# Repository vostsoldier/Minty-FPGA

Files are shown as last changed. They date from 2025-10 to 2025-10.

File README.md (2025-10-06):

# Minty - A ECP5 based devboard with DDR3 RAM
## An introduction
Hey fellas it's Technical here with a cool beans board!!!
I wanted to experiment with FPGAs and RAM at the same time, so I thought, why not just combine the two onto one board!
What a great idea right!!! Hahahahahahhahaha!
But yeah thats how this board came to be...
At the time of writing (10/5/25), the board only has a few key parts needed for it to function..
HOWEVER, I am planning to put more cool stuff onto it, as I have like 150 IO pins left lol...
Feel free to DM technical_. on the Hack Club slack if you have any ideas for what to put!!!

## Features (As of 10/5/25)
- Lattice ECP5 FPGA
  * 44k LUTS
  * 1944 KiB of Embedded Memory
  * 351 KiB of RAM
- DDR3 RAM
  * 2GB
  * DDR3??
- 100 Mhz clock (probably)
- Snazzy Name

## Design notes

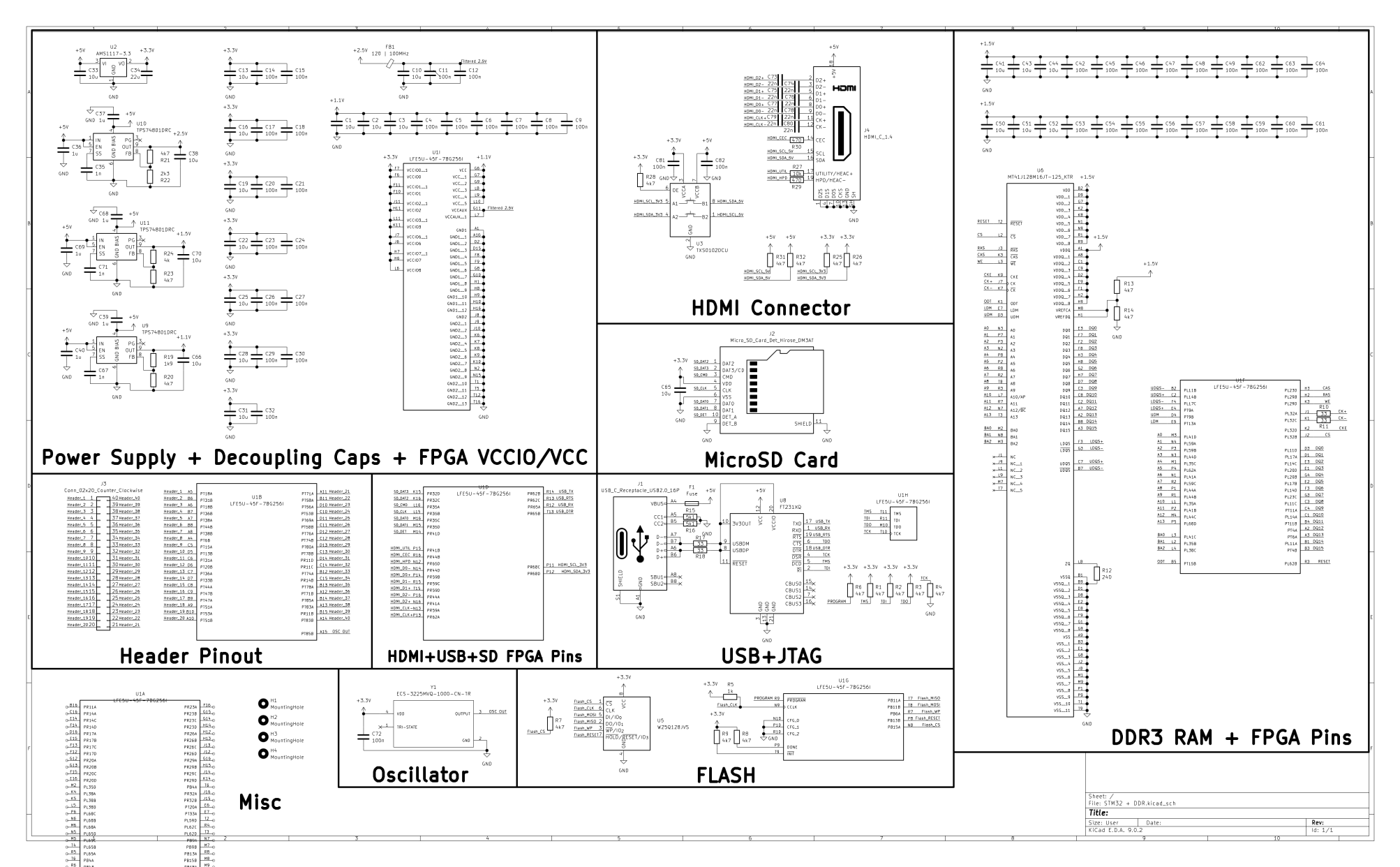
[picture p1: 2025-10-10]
Schematic Image/Minty_Schematic.png

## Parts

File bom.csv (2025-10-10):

Id | Designator | Footprint | Quantity | Designation | LCSC # | Price/unit | Total Price
1 | C35, C67, C71 | 0402_1005 | 3 | 1n | C1523 | 0.0011 | 1.5033
2 | C73, C74, C75, C76, C77, C78, C79, C80 | 0201_0603 | 8 | 22n | C161473 | 0.0076 | 1.5608
3 | C4, C5, C6, C7, C8, C9, C11, C12, C14, C15, C17, C18, C20, C21, C23, C24, C26, C27, C29, C30, C32, C42, C45, C46, C47, C48, C49, C53, C54, C55, C56, C57, C58, C59, C60, C61, C62, C63, C64, C72, C81, C82 | 0201_0603 | 41 | 100n | C49062 | 0.0013 | 1.5533
4 | C36, C37, C39, C40, C68, C69 | 0603_1608 | 6 | 1u | C15849 | 0.0047 | 1.5282
5 | C65 | 0402_1005 | 1 | 10u | C15525 | 0.005 | 1.505
6 | C10, C33, C38, C66, C70 | 0603_1608 | 5 | 10u | C19702 | 0.0056 | 1.528
7 | C34 | 0603_1608 | 1 | 22u | C59461 | 0.0086 | 1.5086
8 | R10, R11, R17, R18 | 0402_1005 | 4 | 33 | C25105 | 0.0006 | 1.5024
9 | R12, R33 | 0603_1608 | 2 | 240 | C23350 | 0.0007 | 1.5014
10 | R29, R30 | 0402_1005 | 2 | 470 | C17710 | 0.0018 | 1.5036
11 | R5 | 0402_1005 | 1 | 1k | C11702 | 0.0005 | 1.5005
12 | R19, R22, R24, R34, | 0402_1005 | 4 | 2k | C4109 | 0.0005 | 1.502
13 | R1, R2, R3, R4, R6, R7, R8, R9, R13, R14, R20, R21, R23, R25, R26, R28, R31, R32 | 0201_0603 | 18 | 4k7 | C138135 | 0.0008 | 1.5144
14 | R15, R16 | 0402_1005 | 2 | 5k1 | C11702 | 0.0005 | 1.501
15 | R27 | 0402_1005 | 1 | 10k | C25744 | 0.0005 | 1.5005
16 | FB1 | 0603_1608 | 1 | 120 | 100MHz | C14709 | 0.0064 | 1.5064
17 | F1 | 0603_1608 | 1 | Fuse | C210357 | 0.0347 | 1.5347
18 | U9, U10, U11 | VSON-10-1EP_3x3mm_P0.5mm_EP1.65x2.4mm_ThermalVias | 3 | TPS74801DRC | C105263 | 0.2225 | 2.1675
19 | U2 | SOT-223-3_TabPin2 | 1 | AMS1117-3.3 | C6186 | 0.1622 | 1.6622
20 | U5 | SOIC-8_5.3x5.3mm_P1.27mm | 1 | W25Q128JVS | C97521 | 1.0605 | 2.5605
21 | U8 | QFN-20-1EP_4x4mm_P0.5mm_EP2.5x2.5mm | 1 | FT231XQ | C132159 | 4.503 | 6.003
22 | U3 | VSSOP-8_2.3x2mm_P0.5mm | 1 | TXS0102DCU | C53434 | 0.1266 | 1.6266
23 | Y1 | OSC_ECS-3225MVQ-1000-CN-TR | 1 | ECS-3225MVQ-1000-CN-TR | C2595933 | 2.217 | 3.717
24 | U1 | BGA256C80P16X16_1400X1400X170 | 1 | LFE5U-45F-7BG256I | C1550826 | 15.8235 | 17.3235
25 | U6 | BGA96C80P6X16_800X1400X120 | 1 | MT41J128M16JT-125_KTR | C426885 | 3.36 | 4.86
26 | J1 | USB_C_Receptacle_GCT_USB4105-xx-A_16P_TopMnt_Horizontal | 1 | USB_C_Receptacle_USB2.0_16P | C2765186 | 0.0563 | 1.5563
27 | J2 | microSD_HC_Hirose_DM3AT-SF-PEJM5 | 1 | Micro_SD_Card_Det_Hirose_DM3AT | C114218 | 1.203 | 2.703
28 | J4 | AMPHENOL_10029449-11RLF | 1 | HDMI_C_1.4 | C427307 |  | 139.8674

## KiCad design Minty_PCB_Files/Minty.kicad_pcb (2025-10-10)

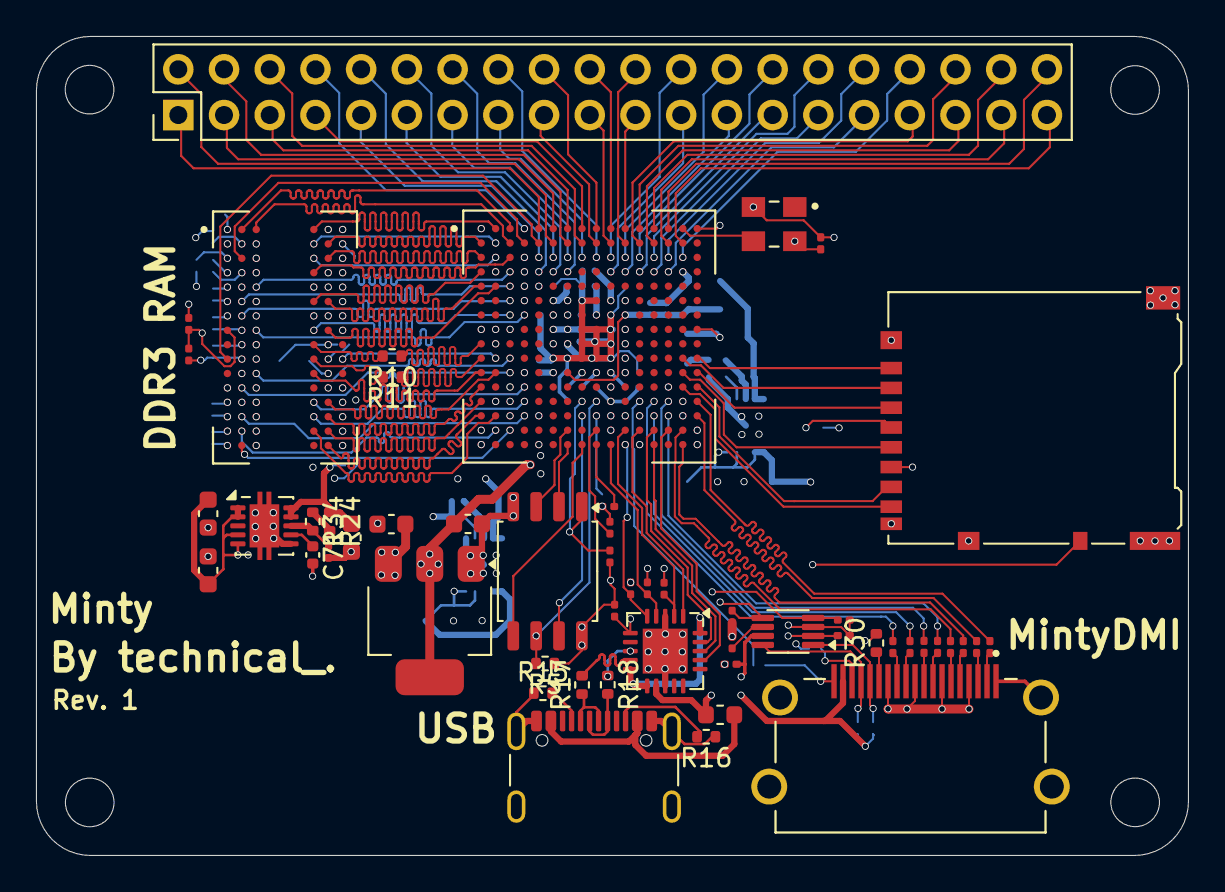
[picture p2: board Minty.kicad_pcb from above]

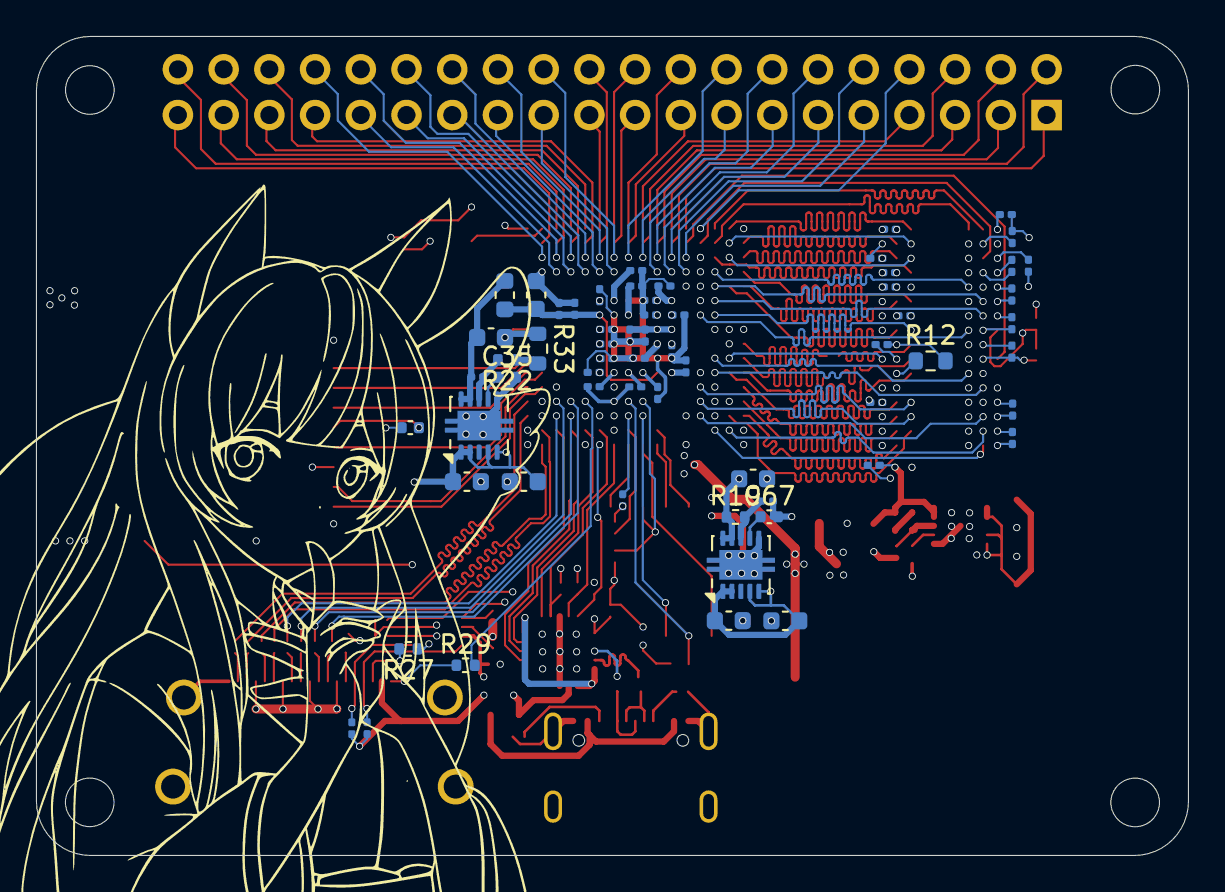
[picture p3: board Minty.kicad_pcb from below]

Board: 6 copper layers, 64.0 x 45.5 mm, 119 parts (62 on the bottom side), 165 nets.

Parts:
C4, C5, C6, C7, C8, C9, C11, C12, C14, C15, C17, C18, C20, C21, C23, C24, C26, C27, C29, C30, C32, C42, C45, C46, C47, C48, C49, C53, C55, C56, C57, C58, C59, C60, C61, C62, C63, C64, C72, C81, C82: 100n; C_0201_0603Metric
C10, C33, C38, C66, C70: 10u; C_0603_1608Metric
C34: 22u; C_0603_1608Metric
C35, C67, C71: 1n; C_0402_1005Metric
C36, C37, C39, C40, C68, C69: 1u; C_0603_1608Metric
C65: 10u; C_0402_1005Metric
C73, C74, C75, C76, C77, C78, C79, C80: 22n; C_0201_0603Metric
F1: Fuse; Fuse_0603_1608Metric
FB1: 120 | 100MHz; L_0603_1608Metric
H1, H2, H3, H4: MountingHole; MountingHole_2.7mm_M2.5
J1: USB_C_Receptacle_USB2.0_16P; USB_C_Receptacle_GCT_USB4105-xx-A_16P_TopMnt_Horizontal
J2: Micro_SD_Card_Det_Hirose_DM3AT; microSD_HC_Hirose_DM3AT-SF-PEJM5
J3: Conn_02x20_Counter_Clockwise; PinHeader_2x20_P2.54mm_Vertical
J4: HDMI_C_1.4; AMPHENOL_10029449-111RLF
R1, R2, R3, R4, R6, R7, R8, R9, R13, R14, R20, R21, R23, R25, R26, R28, R31, R32: 4k7; R_0201_0603Metric
R5: 1k; R_0402_1005Metric
R10, R11, R17, R18: 33; R_0402_1005Metric
R12, R33: 240; R_0603_1608Metric
R15, R16: 5k1; R_0402_1005Metric
R19, R22, R24, R34: 2k; R_0402_1005Metric
R27: 10k; R_0402_1005Metric
R29, R30: 470; R_0402_1005Metric
U1: LFE5U-45F-7BG256I; BGA256C80P16X16_1400X1400X170
U2: AMS1117-3.3; SOT-223-3_TabPin2
U3: TXS0102DCU; VSSOP-8_2.3x2mm_P0.5mm
U5: W25Q128JVS; SOIC-8_5.3x5.3mm_P1.27mm
U6: MT41J128M16JT-125_KTR; BGA96C80P6X16_800X1400X120
U8: FT231XQ; QFN-20-1EP_4x4mm_P0.5mm_EP2.5x2.5mm
U9, U10, U11: TPS74801DRC; VSON-10-1EP_3x3mm_P0.5mm_EP1.65x2.4mm_ThermalVias
Y1: ECS-3225MVQ-1000-CN-TR; OSC_ECS-3225MVQ-1000-CN-TR

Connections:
+1.1V: C4.1, C5.1, C6.1, C7.1, C8.1, C9.1, C66.1, R19.1, U1.G6 (VCC), U1.G7 (VCC__1), U1.G9 (VCC__2), U1.L8 (VCC__3), U1.L9 (VCC__4), U1.L10 (VCC__5), U9.9 (OUT), U9.10 (OUT)
+1.5V: C42.1, C45.1, C46.1, C47.1, C48.1, C49.1, C53.1, C55.1, C56.1, C57.1, C58.1, C59.1, C60.1, C61.1, C62.1, C63.1, C64.1, C70.1, R13.1, R24.1, U6.A1 (VDDQ), U6.A8 (VDDQ__1), U6.B2 (VDD), U6.C1 (VDDQ__2), U6.C9 (VDDQ__3), U6.D2 (VDDQ__4), U6.D9 (VDD__1), U6.E9 (VDDQ__5), U6.F1 (VDDQ__6), U6.G7 (VDD__2), U6.H2 (VDDQ__7), U6.H9 (VDDQ__8), U6.K2 (VDD__3), U6.K8 (VDD__4), U6.N1 (VDD__5), U6.N9 (VDD__6), U6.R1 (VDD__7), U6.R9 (VDD__8), U11.9 (OUT), U11.10 (OUT)
+2.5V: C38.1, FB1.1, R21.2, U10.9 (OUT), U10.10 (OUT)
+3.3V: C14.1, C15.1, C17.1, C18.1, C20.1, C21.1, C23.1, C24.1, C26.1, C27.1, C29.1, C30.1, C32.1, C34.1, C65.2, C72.1, C81.1, J2.4 (VDD), R1.1, R2.1, R3.1, R5.1, R6.1, R7.1, R8.1, R9.1, R25.1, R26.1, R28.1, U1.F6 (VCCIO0), U1.F7 (VCCIO0__1), U1.F10 (VCCIO1), U1.F11 (VCCIO1__1), U1.H6 (VCCIO7), U1.H7 (VCCIO7__1), U1.H11 (VCCIO2), U1.J6 (VCCIO6), U1.J7 (VCCIO6__1), U1.J11 (VCCIO2__1), U1.K11 (VCCIO3), U1.L6 (VCCIO8), U1.L11 (VCCIO3__1), U2.2 (VO), U3.3 (VCCA), U5.8 (VCC), Y1.4 (VDD)
+5V: C33.1, C36.1, C37.2, C39.2, C40.1, C68.2, C69.1, C82.1, F1.2, J4.18 (+5V), R31.1, R32.1, U2.3 (VI), U3.7 (VCCB), U8.12 (VCC), U9.1 (IN), U9.2 (IN), U9.4 (BIAS), U9.5 (EN), U10.1 (IN), U10.2 (IN), U10.4 (BIAS), U10.5 (EN), U11.1 (IN), U11.2 (IN), U11.4 (BIAS), U11.5 (EN)
/A0: U1.M3 (PL41D), U6.N3 (A0)
/A1: U1.N4 (PL59A), U6.P7 (A1)
/A2: U1.P3 (PL59B), U6.P3 (A2)
/A3: U1.N3 (PL44D), U6.N2 (A3)
/A4: U1.M1 (PL35C), U6.P8 (A4)
/A5: U1.P4 (PL62A), U6.P2 (A5)
/A6: U1.N1 (PL41A), U6.R8 (A6)
/A7: U1.R2 (PL59C), U6.R2 (A7)
/A8: U1.P1 (PL44A), U6.T8 (A8)
/A9: U1.R1 (PL44B), U6.R3 (A9)
/A10: U1.L1 (PL35A), U6.L7 (A10/AP)
/A11: U1.P2 (PL41B), U6.R7 (A11)
/A12: U1.M4 (PL44C), U6.N7 (A12/~BC)
/A13: U1.P5 (PL68D), U6.T3 (A13)
/BA0: U1.L3 (PL41C), U6.M2 (BA0)
/BA1: U1.L2 (PL35B), U6.N8 (BA1)
/BA2: U1.L4 (PL38C), U6.M3 (BA2)
/CAS: U1.H3 (PL23D), U6.K3 (~CAS)
/CK+: R10.2, U6.J7 (CK)
/CK-: R11.2, U6.K7 (~CK)
/CKE: U1.K2 (PL32D), U6.K9 (CKE)
/CS: U1.J2 (PL32B), U6.L2 (~CS)
/DQ0: U1.D3 (PL11D), U6.E3 (DQ0)
/DQ1: U1.D1 (PL17A), U6.F7 (DQ1)
/DQ2: U1.E3 (PL14C), U6.F2 (DQ2)
/DQ3: U1.E1 (PL20D), U6.F8 (DQ3)
/DQ4: U1.G4 (PL20B), U6.H3 (DQ4)
/DQ5: U1.E2 (PL17B), U6.H8 (DQ5)
/DQ6: U1.F3 (PL14D), U6.G2 (DQ6)
/DQ7: U1.G3 (PL23C), U6.H7 (DQ7)
/DQ8: U1.C3 (PL11C), U6.D7 (DQ8)
/DQ9: U1.C4 (PT11A), U6.C3 (DQ9)
/DQ10: U1.C1 (PL14A), U6.C8 (DQ10)
/DQ11: U1.B4 (PT11B), U6.C2 (DQ11)
/DQ12: U1.A2 (PT4A), U6.A7 (DQ12)
/DQ13: U1.A3 (PT6A), U6.A2 (DQ13)
/DQ14: U1.B1 (PL11A), U6.B8 (DQ14)
/DQ15: U1.B3 (PT4B), U6.A3 (DQ15)
/Filtered 2.5V: C10.1, C11.1, C12.1, FB1.2, U1.G11 (VCCAUX), U1.L7 (VCCAUX__1)
/Flash_CLK: R5.2, U1.N9 (CCLK), U5.6 (CLK)
/Flash_CS: R7.2, U1.N8 (PB15A), U5.1 (~CS)
/Flash_MISO: U1.T7 (PB11A), U5.2 (DO/IO_{1})
/Flash_MOSI: U1.T8 (PB11B), U5.5 (DI/IO_{0})
/Flash_RESET: U1.P8 (PB13B), U5.7 (~HOLD/~RESET/IO_{3})
/Flash_WP: U1.R7 (PB6A), U5.3 (~WP/IO_{2})
/HDMI_CEC: R30.2, U1.R16 (PR44B)
/HDMI_CLK+: C79.2, U1.P13 (PR62A)
/HDMI_CLK-: C80.2, U1.N13 (PR59A)
/HDMI_D0+: C77.2, U1.P14 (PR59B)
/HDMI_D0-: C78.2, U1.N14 (PR44D)
/HDMI_D1+: C75.2, U1.T15 (PR59D)
/HDMI_D1-: C76.2, U1.R15 (PR59C)
/HDMI_D2+: C73.2, U1.N16 (PR41A)
/HDMI_D2-: C74.2, U1.P16 (PR44A)
/HDMI_HPD: R29.2, U1.N12 (PR65D)
/HDMI_SCL_3V3: R25.2, U1.P11 (PR68C), U3.5 (A1)
/HDMI_SCL_5V: J4.15 (SCL), R31.2, U3.1 (B2)
/HDMI_SDA_3V3: R26.2, U1.P12 (PR68D), U3.4 (A2)
/HDMI_SDA_5V: J4.16 (SDA), R32.2, U3.8 (B1)
/HDMI_UTIL: R27.1, U1.P15 (PR41B)
/Header_1: J3.1, U1.A5 (PT18A)
/Header_2: J3.2, U1.B6 (PT31B)
/Header_3: J3.3, U1.A6 (PT18B)
/Header_4: J3.4, U1.B7 (PT36B)
/Header_5: J3.5, U1.A7 (PT38A)
/Header_6: J3.6, U1.B8 (PT44B)
/Header_7: J3.7, U1.A8 (PT38B)
/Header_8: J3.8, U1.A4 (PT6B)
/Header_9: J3.9, U1.C5 (PT15A)
/Header_10: J3.10, U1.D5 (PT13B)
/Header_11: J3.11, U1.C6 (PT31A)
/Header_12: J3.12, U1.D6 (PT20B)
/Header_13: J3.13, U1.C7 (PT36A)
/Header_14: J3.14, U1.D7 (PT33B)
/Header_15: J3.15, U1.C8 (PT44A)
/Header_16: J3.16, U1.C9 (PT47B)
/Header_17: J3.17, U1.B9 (PT47A)
/Header_18: J3.18, U1.A9 (PT51A)
/Header_19: J3.19, U1.B10 (PT53A)
/Header_20: J3.20, U1.A10 (PT51B)
/Header_21: J3.21, U1.A11 (PT71A)
/Header_22: J3.22, U1.B11 (PT58A)
/Header_23: J3.23, U1.D10 (PT56A)
/Header_24: J3.24, U1.C10 (PT53B)
/Header_25: J3.25, U1.D11 (PT69A)
/Header_26: J3.26, U1.C11 (PT58B)
/Header_27: J3.27, U1.D12 (PT76A)
/Header_28: J3.28, U1.C12 (PT74B)
/Header_29: J3.29, U1.D13 (PT80A)
/Header_30: J3.30, U1.C13 (PT78B)
/Header_31: J3.31, U1.D14 (PR11D)
/Header_32: J3.32, U1.C14 (PR11C)
/Header_33: J3.33, U1.B12 (PT74A)
/Header_34: J3.34, U1.C15 (PR14B)
/Header_35: J3.35, U1.B13 (PT78A)
/Header_36: J3.36, U1.A12 (PT71B)
/Header_37: J3.37, U1.B14 (PT85A)
/Header_38: J3.38, U1.A13 (PT83A)
/Header_39: J3.39, U1.B15 (PR11B)
/Header_40: J3.40, U1.A14 (PT83B)
/LDM: U1.E5 (PT13A), U6.E7 (LDM)
/LDQS+: U1.E4 (PT9A), U6.F3 (LDQS)
/LDQS-: U1.F4 (PL17C), U6.G3 (~LDQS)
/ODT: U1.B5 (PT15B), U6.K1 (ODT)
/OSC OUT: U1.A15 (PT85B), Y1.3 (OUTPUT)
/PROGRAM: R6.2, U1.R9 (~PROGRAM)
/RAS: U1.H2 (PL29B), U6.J3 (~RAS)
/RESET: U1.R3 (PL62B), U6.T2 (~RESET)
/SD_CLK: J2.5 (CLK), U1.L15 (PR35B)
/SD_CMD: J2.3 (CMD), U1.L16 (PR35A)
/SD_DAT0: J2.7 (DAT0), U1.M16 (PR35C)
/SD_DAT1: J2.8 (DAT1), U1.M15 (PR35D)
/SD_DAT2: J2.1 (DAT2), U1.K16 (PR32C)
/SD_DAT3: J2.2 (DAT3/CD), U1.K15 (PR32D)
/SD_DET: J2.10 (DET_A), U1.M14 (PR41D)
/TCK: R4.1, U1.T10 (TCK), U8.4 (~DSR)
/TDI: R2.2, U1.R11 (TDI), U8.2 (~RI)
/TDO: R3.2, U1.M10 (TDO), U8.6 (~CTS)
/TMS: R1.2, U1.T11 (TMS), U8.5 (~DCD)
/UDM: U1.D4 (PT9B), U6.D3 (UDM)
/UDQS+: U1.C2 (PL14B), U6.C7 (UDQS)
/UDQS-: U1.B2 (PL11B), U6.B7 (~UDQS)
/USB_DTR: U1.T13 (PR65B), U8.18 (~DTR)
/USB_RTS: U1.R13 (PR62C), U8.19 (~RTS)
/USB_RX: U1.R12 (PR65A), U8.1 (RXD)
/USB_TX: U1.R14 (PR62B), U8.17 (TXD)
/WE: U1.K3 (PL29D), U6.L3 (~WE)
GND: C4.2, C5.2, C6.2, C7.2, C8.2, C9.2, C10.2, C11.2, C12.2, C14.2, C15.2, C17.2, C18.2, C20.2, C21.2, C23.2, C24.2, C26.2, C27.2, C29.2, C30.2, C32.2, C33.2, C34.2, C35.2, C36.2, C37.1, C38.2, C39.1, C40.2, C42.2, C45.2, C46.2, C47.2, C48.2, C49.2, C53.2, C55.2, C56.2, C57.2, C58.2, C59.2, C60.2, C61.2, C62.2, C63.2, C64.2, C65.1, C66.2, C67.2, C68.1, C69.2, C70.2, C71.2, C72.2, C81.2, C82.2, J1.A1 (GND), J1.B1 (GND), J1.S1 (SHIELD), J2.6 (VSS), J2.9 (DET_B), J2.11 (SHIELD), J4.1 (D2S), J4.4 (D1S), J4.7 (D0S), J4.10 (CKS), J4.13 (GND), R4.2, R12.2, R14.2, R15.1, R16.1, R20.2, R23.2, R33.1, U1.A1 (GND1), U1.A16 (GND1__1), U1.D2 (GND1__2), U1.D15 (GND1__3), U1.F8 (GND1__4), U1.F9 (GND1__5), U1.G8 (GND1__6), U1.G10 (GND1__7), U1.H1 (GND1__8), U1.H8 (GND1__9), U1.H9 (GND1__10), U1.H10 (GND1__11), U1.H16 (GND1__12), U1.J8 (GND2), U1.J9 (GND2__1), U1.J10 (GND2__2), U1.K6 (GND2__3), U1.K7 (GND2__4), U1.K8 (GND2__5), U1.K9 (GND2__6), U1.K10 (GND2__7), U1.N2 (GND2__8), U1.N10 (CFG_0), U1.N15 (GND2__9), U1.P10 (CFG_1), U1.R10 (CFG_2), U1.T1 (GND2__10), U1.T5 (GND2__11), U1.T12 (GND2__12), U1.T16 (GND2__13), U2.1 (GND), U3.2 (GND), U5.4 (GND), U6.A9 (VSS), U6.B1 (VSSQ), U6.B3 (VSS__1), U6.B9 (VSSQ__1), U6.D1 (VSSQ__2), U6.D8 (VSSQ__3), U6.E1 (VSS__2), U6.E2 (VSSQ__4), U6.E8 (VSSQ__5), U6.F9 (VSSQ__6), U6.G1 (VSSQ__7), U6.G8 (VSS__3), U6.G9 (VSSQ__8), U6.J2 (VSS__4), U6.J8 (VSS__5), U6.M1 (VSS__6), U6.M9 (VSS__7), U6.P1 (VSS__8), U6.P9 (VSS__9), U6.T1 (VSS__10), U6.T9 (VSS__11), U8.3 (GND), U8.13 (GND), U8.21 (GND), U9.6 (GND), U9.11 (GND), U10.6 (GND), U10.11 (GND), U11.6 (GND), U11.11 (GND), Y1.2 (GND)
unnamed: F1.1, J1.A4 (VBUS), J1.B4 (VBUS)
unnamed: J1.A5 (CC1), R15.2
unnamed: J1.B5 (CC2), R16.2
unnamed: J1.A6 (D+), J1.B6 (D+), R18.2
unnamed: J1.A7 (D-), J1.B7 (D-), R17.1
unnamed: J4.14 (CEC), R30.1
unnamed: C79.1, J4.11 (CK+)
unnamed: C80.1, J4.12 (CK-)
unnamed: C77.1, J4.8 (D0+)
unnamed: C78.1, J4.9 (D0-)
unnamed: C75.1, J4.5 (D1+)
unnamed: C76.1, J4.6 (D1-)
unnamed: C73.1, J4.2 (D2+)
unnamed: C74.1, J4.3 (D2-)
unnamed: J4.19 (HPD/HEAC-), R29.1
unnamed: J4.17 (UTILITY/HEAC+), R27.2
unnamed: R22.1, R33.2
unnamed: R24.2, R34.1
unnamed: R10.1, U1.J1 (PL32A)
unnamed: R11.1, U1.K1 (PL32C)
unnamed: R8.2, U1.P9 (DONE)
unnamed: R9.2, U1.T9 (~INIT)
unnamed: R28.2, U3.6 (OE)
unnamed: R13.2, R14.1, U6.H1 (VREFDQ), U6.M8 (VREFCA)
unnamed: R12.1, U6.L8 (ZQ)
unnamed: R17.2, R18.1, U8.8 (USBDP), U8.9 (USBDM), U8.10 (3V3OUT), U8.11 (~RESET), U8.20 (VCCIO)
unnamed: R19.2, R20.1, U9.8 (FB)
unnamed: C67.1, U9.7 (SS)
unnamed: R21.1, R22.2, U10.8 (FB)
unnamed: C35.1, U10.7 (SS)
unnamed: R23.1, R34.2, U11.8 (FB)
unnamed: C71.1, U11.7 (SS)

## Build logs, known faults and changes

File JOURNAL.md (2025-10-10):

<!--
  ===================    !!READ THIS NOTICE!!   ====================
  DO NOT edit this file manually. Your changes WILL BE OVERWRITTEN!
  This journal is auto generated and updated by Hack Club Blueprint.
  To edit this file, please edit your journal entries on Blueprint.
  ==================================================================
-->

This is my journal of the design and building process of **Minty FPGA**.  
You can view this journal in more detail on **Hack Club Blueprint** [here](https://blueprint.hackclub.com/projects/173).

## 10/4/2025 9:10 PM - Started the FPGA schematic + power source + flash memory!  



Added decoupling capacitors for VCCIO, VCC and a filtering system for VCCAUX.
Tied all relevant VSS/VSSQ pins to ground, as per standard practice.
Decided on components for the power source, and chose to use the AMS1117 (Fixed), for the main power supply, and then various TLV713xxPDBV modules for smaller voltage rails (DDR RAM + FPGA).
Chose the W25Q128JVS, as this was a flash that was supported by the ECP5.   

## 10/4/2025 9:14 PM - Finished flash memory + JTAG  



Added net labels and connected the pins of the flash memory (did not do WP or RESET as they don't have specific FPGA pins). 
Initializing the JTAG was easy, as they just needed a couple of pullups/pulldowns!
I also decided on the RAM module that I wanted to use, which was the MT41J128M16JT-125_KTR. This is a 2GB DDR3 memory, for only ~$3, which is actually pretty affordable!  

## 10/4/2025 9:18 PM - Finished RAM schematic + thoughts about potential routing.  




Building off of the RAM module that I chose, I took a look at the reference manual/datasheet, and mapped the pins to the particular FPGA pin that was needed!
I also added a bunch of decoupling caps since I needed a really stable and clean power source to the RAM. 
Address and Data pins did not have a specific pin to map to, so I assigned it in a logical way that would make it the most easiest to route. 
I also made sure to make a mental note to do impedance (50 ohms) and length matching.  

## 10/4/2025 9:24 PM - Routed the DDR3 RAM (DID NOT DO POWER YET)  

Screenshot 2025-10-04 at 9.19.26 PM.png
Screenshot 2025-10-04 at 9.19.43 PM.png
Screenshot 2025-10-04 at 9.19.54 PM.png
Screenshot 2025-10-04 at 9.20.00 PM.png

Keeping in mind the strict impedance (50 ohms) and length matching (clock + data + address traces), I started and finished the routing today. (This should be the most up to date thing for now). 
I put some 33 ohm resistors to improve ringing resistance, and provide a termination point for the clock signals. Address did not need resistors, even though they are "recommended" as the trace lengths were under 1 inch! 
I had to spam skew tuning because most traces had to be length matches and my eyes just see squiggly lines....
But yeah this was worth the effort and tomorrow I have to suffer doing power (backside of the board...)  

## 10/5/2025 10 AM - Finished DDR3 Routing + USB Serial Schema   




So I think I violated some common conventions of routing but here I am!!!
Sadly I had to do via on pad for the DDR3 ram power, since they are decouplings and I can't place them too far...
After that nightmare was over, I started on the USB + USB serial converter schematic since it was a pretty important portion to me! I took a look at the datasheet, and pin mapped relevantly!
I also did the microSD schematic since it was decently easy, and I was really familiar with it!
I'll probably start routing a bit later during the day!  

## 10/5/2025 1 PM - Routed USB + Flash Memory  



I finished routing all of the USB and flash memory components!!!
I didn't attach a picture, but I mapped all of the relevant usb/flash pins to FPGA GPIOs. I tried my best to fanout the BGA in a way that saved most of the GPIO pins. 
Remembering to keep 90 differential pair impedance for the USB traces, and thick traces for the power traces!
I still need to do power, which might take alot of time :pensive:!  

## 10/5/2025 4 PM - Placement + Routing of Caps + Power regulators  




For this journal entry, I finished doing all of the decoupling caps on the FPGA. Standard rule of 1 100n cap per power pin and a few 10u spread out. 
The decoupling cap layout is a bit messy, but it is what it is :///
I also did the routing of the power supply regulators. I didn't fully connect them to the FPGA/power plane yet, but it should just be a couple of copper pours and traces away!   

## 10/5/2025 7 PM - Revised power supply/regulation + routing (TY TO CYAO!!!)  




After talking with Cyao, a neighborhood FPGA expert, I realized that I could have optimized my component selection! 
Taking into account his feedback, I completely changed all of the TLV series *fixed* linear regulators to TPS series linear *adjustable* regulators. It added a few more discrete components, but it saved me a ton of money on JLC's extended part reel fee!
I didn't add vias to the GND pads of the modules, since I still had to figure out where I would place them, and how I would link them up to the FPGA.  

## 10/5/2025 8 PM - Finished routing all of the power yahoo  



As you can see in the picture, I finished routing and placing the linear regulator modules. It feels a bit unoptimized to me, but for now its pretty functional and it works!
I hate how there is empty space there, but it is a "oh well can't do much about it" moment.
I'll probably clean up the vias since they look uneven, but overall a decent idea. 
I forgot about the clock, so I have to make the schematic for that, but that is easy!!!
I feel like I need more of a bang on the board, so tomorrow will just be tidying up and thoughts!   

## 10/5/2025 11 PM - Created/Routed osc schematic + optimization  




I finally added the 100 MHz oscillator. I chose the ECS-3225MVQ-1000-CN-TR, since it was fairly cheap, but also reputable. The oscillation waves were very clean, suitable for my DDR3 clock references!
I also optimized my power supply placement a bit, as I realized I had just enough space to squeeze in my AMS-1117 (3.3V fixed). 
The design looked more clean overall!

I fixed some traces as well, opting for a more professional and efficient route. 

If you read this, I would appreciate it if you could DM me some ideas about what I should add next, like sensors or anything really cool!  

## 10/6/2025 11 AM - Finished routing microSD + QOL improvements!  



Heyo guys, I finished routing all of the microSD pins!!!
This part was a bit easy, since microSD doesn't need too much strict requirements, so I routed the traces cleanly, and made sure that they were decently length matchedish.
I was thinking about moving the USB, and moving a few components to make the board smaller, but I did not want to risk getting too much interference (two high speed signals right next to each other (DDR3 + USB is not a good combo)... 
I fixed up some traces, as I forgot to send 5V traces to the power regulators. I used a simple copper pour, (maybe three different copper pours on one layer is okay??) and did multiple vias + thick traces as the current was pretty big.  

## 10/6/2025 11:20 PM - Routed HDMI connector + schematic  




Okay before I start, I just want say. Cramming a HDMI connector into BGA pads is not fun. At all.
I basically removed the entire microsd for now, since HDMI had to be closer to the FPGA cuz signal priority + high speed signals etc etc... 
I'll probably put microSD at a later time, maybe above the HDMI connector. 
I still have some space for one more cool thing, so I need more ideas lol!!!  

## 10/6/2025 11:43 PM - Finished routing microSD (for real this time)  



So I finished routing the microSD component, and pin mapped to the preferred pins. I think that this will be the last major feature, and that I won't add any more... (maybe)...
I still need to connect a few power pins, so I will do some revisions + add a few LEDs tommorow!
Otherwise the board should be almost complete!!!  

## 10/7/2025 8 AM - Finished routing everything!!!!  



It's here!!! The finished routed version of the Minty board!!!
All I did were a few minor changes, such as cleaning up vias, improving traces, connecting GND + Power pins. 
Not too much, but it was definitely the more annoying portion...
After I clean up my schematic and get reviews from professionals, I should be able to ship the board!!!  

## 10/7/2025 6 PM - Added pin headers + cleaned up routing + other QOL  



I added a 40 pin header, perfect for people who want to experiment using io pins!
Added a couple of mounting holes and filleted edge cuts!
Moved a couple of components around a bit to make the design look a bit more cleaner, and messed with the traces to make them look more clean/efficent. 
I may or may not change the FPGA decoupling caps later, as it is a bit messyish/  

## 10/8/2025 - Polished up the schematic + waiting for professional review  



So after last update, where I finished up the routing, this time I tried to fix up the schematic to make it look pretty for professionals to review. I sent it over to KiCAD's official server, where experienced people will look at it!

Cleaning up the schematic was ridicously annoying, as I had to move all of the dang FPGA pins around... That was a whole time with carpal tunnel...

After I get a review of my schematic + routing, I'll fix all of the errors on the next update!  

## 10/9/2025 - Feedback implementation + silkscreen  




I got feedback from professionals from the KiCAD official server, and there were no major faults!!! Hip hip hooray lol!!!
I fixed a few things like adding more vias since they don't cost anything to add, fixing up some traces, double checking that values were correct, and adding some silkscreen so that the board looked nice/I knew what was what!  

## 10/10/2025 - Finished BOM + Gerbers  



Hey everyone!
I recently finished the BOM and finished organizing all of the Gerbers. As per Blueprint instructions, I have uploaded all of them to the github repo, so feel free to check them out. For now I haven't uploaded all of the libraries/3d models I have used for the components, which I will do at a later date. 
Next stop will be finding a suitable price for everything!
